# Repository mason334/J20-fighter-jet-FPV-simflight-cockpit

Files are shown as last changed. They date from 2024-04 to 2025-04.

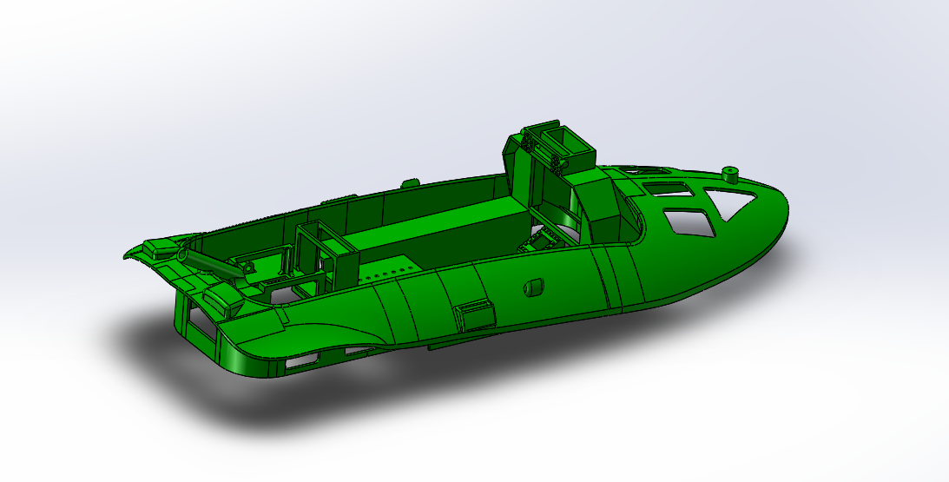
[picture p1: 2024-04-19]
3d模型 2024_4_19/座舱3d模型/座舱 spi tft 版.png

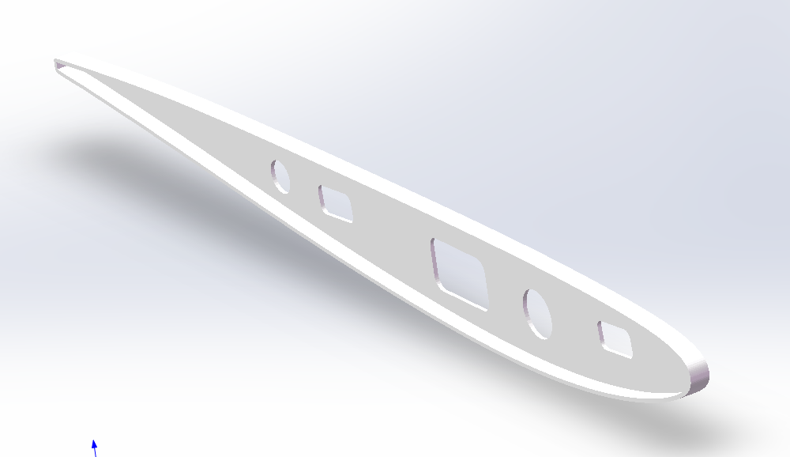
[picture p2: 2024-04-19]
3d模型 2024_4_19/新小胖3d配件/left_airfol.png

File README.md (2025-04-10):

# 5代战斗机模拟飞行座舱
## J20战机模拟座舱 Chengdu J20 fighter jet FPV simflight cockpit  
由于各种原因，最终只能有少部分人人成为飞行员，翱翔在蓝天。但是，我们依然向往飞行！  
多亏半导体和无线电技术的高速发展，已经让FPV飞行成为可能。  
现在，我们把飞行体验往前再推进一步。  
采用这套模拟座舱系统，通过3D打印和数字图传系统，你可以坐进模拟座舱，体验身临其境的战斗机驾驶乐趣。  
这套J20模拟座舱系统由硬件和软件组成。  

硬件由4部分组成  
- 机舱：包含显示器、散热风扇、DJI O3天空端等安装座。
- 舱盖：包括舱盖框架和风挡文件。
- 显示器：1块0.69寸OLDE显示器， 1块0.42寸OLED显示器，和1块2.2寸主tft lcd显示器或者1.9寸amoled主显示器。
- 显示器控制单片机：ESP32-S3  

软件部分是一套用arduino编程语言编写的ESP32-S3控制程序。ESP32-S3通过UART串口与飞控通信，采用mavlink协议。  
通过mavlink协议读取的数据，ESP32-S3驱动3块显示器显示我们想要的信息，包括姿态仪、图案、各种飞行数据。  
**这样就给一个FPV座舱注入了灵魂：实时、动态的飞行数据。**  
你甚至可以不看图传眼镜里面的OSD数据，直接通过座舱的显示器实现仪表飞行。  

## 准备工作
使用这套J20模拟座舱前，你需要具备基础的航模飞行经验，并且具备以下FPV基础硬件条件：  
- **一架天捷力 新小胖 载机**
- 一套航模飞机遥控系统  
- 一套DJI O3数字图传系统（座舱模型是根据O3数字图传系统设计的，如果采用其他图传系统，需要自行修改座舱模型）  
- 能够定义串口通信协议的飞控：例如支持ardupilot固件或者iNav固件的飞控。用于座舱和飞控的数据通信。  
- DJI FPV飞行眼镜  
如果你不具备上述条件，说明你还不适合直接开展仿真模拟FPV飞行。请先学习航模目视飞行，并学会基础的FPV知识再回来。


完成以上准备工作后，你离仿真模拟飞行的距离只差几步了，而且总共花费不到300元人民币（TFT版）。  
## 第零步，选择你喜欢的座舱版本
- 目前开发了两个版本的座舱。
- 一个是采用2.2寸tft显示屏的座舱，主显示屏成本较低（约35元）。使用文件夹“spi_tft_320_240_cockpit_20240419”里面的代码驱动2.2寸 tft显示屏。
- 另外一个版本是采用amoled的显示屏，主显示屏成本高（约190元），结果是比例更协调，亮度更高，颜色更鲜艳。使用文件夹“cockpit_lilygo_2024_4_13”里面的代码驱动lilygo amoled显示屏。这个版本的座舱还配备了光学HUD，需要一块单独的esp32单片机来驱动。使用文件夹“oled_hud_attitude_indicator_2024_4_9”里的代码来驱动这个光学hud。
- 相关视频效果见up主B站相关视频，传送连接https://space.bilibili.com/1096820983

## 第一步 打印座舱和舱盖。按照风挡文件，裁剪孰料片，制作风挡  

由于TFT LCD屏幕在阳光下亮度不够，直接在阳光下无法看清屏幕。所以风挡采用遮光塑料片，用于阳光下飞行使用。也可采用透明塑料片制作，非强光下飞行使用。

## 第二步 购买电子设备  
- ESP32-s3单片机（源地工作室，esp32-S3 N16R8)
- 信利光电 0.69寸 96x16 OLED SSD1306
- 信利光电0.42 72x40 OLED SSD1306
- 信泰微电子 2.2寸 ILI9341 SPI TFT LCD （适配SPI TFT 版座舱）
- Lilygo T-display s3 1.9寸amoled 显示屏 （适配Lilygo AMOLED版座舱）
- 光学HUD使用的显示屏采用1.5寸Futaba ELW501AAR 128*128 OLED显示屏（日本进口灰阶oled屏，类似的SSD1327芯片驱动的128X128OLED也可以）
- 盈讯 3510 液压轴承 散热风扇

## 第三步 焊接  
根据控制程序要求，焊接3块屏幕和ESP32单片机的接线。焊接ESP32单片机与飞控通信的排线。
# Lilygo T-display s3 amoled 显示屏无需焊接，屏幕和esp32单片机已经连接好

# 2.2寸显示屏接线如下  
显示屏引脚 &nbsp; &nbsp; ESP32引脚  
MISO &nbsp; &nbsp; &nbsp; &nbsp; &nbsp; &nbsp; &nbsp;13  
MOSI &nbsp; &nbsp; &nbsp; &nbsp; &nbsp; &nbsp; &nbsp;11  
SCLK &nbsp; &nbsp; &nbsp; &nbsp; &nbsp; &nbsp; &nbsp; 12  
CS &nbsp; &nbsp; &nbsp; &nbsp; &nbsp; &nbsp; &nbsp; &nbsp; &nbsp; 10  // Chip select control pin  
DC &nbsp; &nbsp; &nbsp; &nbsp; &nbsp; &nbsp; &nbsp; &nbsp; &nbsp; 7  // Data Command control pin  
RST &nbsp; &nbsp; &nbsp; &nbsp; &nbsp; &nbsp; &nbsp; &nbsp; 4  // Reset pin (could connect to RST pin)  
LED &nbsp; &nbsp; &nbsp; &nbsp; &nbsp; &nbsp; &nbsp; &nbsp; 3V3  
VCC &nbsp; &nbsp; &nbsp; &nbsp; &nbsp; &nbsp; &nbsp; &nbsp; 3V3   
GND &nbsp; &nbsp; &nbsp; &nbsp; &nbsp; &nbsp; &nbsp; &nbsp; GND  

# 0.69寸96x16显示屏接线如下  
显示屏引脚 &nbsp; &nbsp; &nbsp; ESP32引脚  
SCL/SCK &nbsp; &nbsp; &nbsp; &nbsp; &nbsp; &nbsp; 2  
SDA &nbsp; &nbsp; &nbsp; &nbsp; &nbsp; &nbsp; &nbsp; &nbsp; &nbsp; 42  
VCC &nbsp; &nbsp; &nbsp; &nbsp; &nbsp; &nbsp; &nbsp; &nbsp; &nbsp; 3V3  
GND &nbsp; &nbsp; &nbsp; &nbsp; &nbsp; &nbsp; &nbsp; &nbsp; &nbsp; GND  
# 0.42寸72x40显示屏接线如下  
显示屏引脚 &nbsp; &nbsp; &nbsp; ESP32引脚  
SCL/SCK &nbsp; &nbsp; &nbsp; &nbsp; &nbsp; &nbsp;20  
SDA &nbsp; &nbsp; &nbsp; &nbsp; &nbsp; &nbsp; &nbsp; &nbsp; &nbsp; 21  
VCC &nbsp; &nbsp; &nbsp; &nbsp; &nbsp; &nbsp; &nbsp; &nbsp; &nbsp; 3V3  
GND &nbsp; &nbsp; &nbsp; &nbsp; &nbsp; &nbsp; &nbsp; &nbsp; &nbsp; GND

# 飞控串口通讯接线
ESP32引脚 &nbsp; &nbsp; &nbsp; 飞控串口引脚  
RX &nbsp; &nbsp; &nbsp; &nbsp; &nbsp; &nbsp; &nbsp; &nbsp; &nbsp; &nbsp; TX  
GND &nbsp; &nbsp; &nbsp; &nbsp; &nbsp; &nbsp; &nbsp; &nbsp; &nbsp;GND  



## 第四步 上传代码，点亮屏幕  
将代码下载后，放到arduino项目目录下，文件夹名称与主程序文件名称一致（J20-fighter-jet-FPV-simflight-cockpit）  
安装ESP32开发板：ESP32S3 Dev Module  
根据主程序代码中include部分要求，安装所需的库文件。
Arduino已经有匹配的MAVlink库了，可以直接在arduino ide中下载安装，不再需要手动下载导入。
通过机载5V电源，给ESP32单片机供电，点亮屏幕。 **尽量不要用飞控给ESP32供电，避免飞控电流过载。**  
将代码上传到ESP32单片机。注意esp32-S3 N16R8开发板有两个type c接口，上传代码时只能用com这个口（type c接口背面有标注）  
将串口接上飞控，飞控对应的串口选择**mavlink 1**协议，获得屏幕数据。    
- SPI TFT LCD 版座舱

- Lilygo AMOLED版座舱


## 第五步 安装其他设备  
将天空端、散热风扇安装好，然后座舱盖固定到机舱上，完成安装








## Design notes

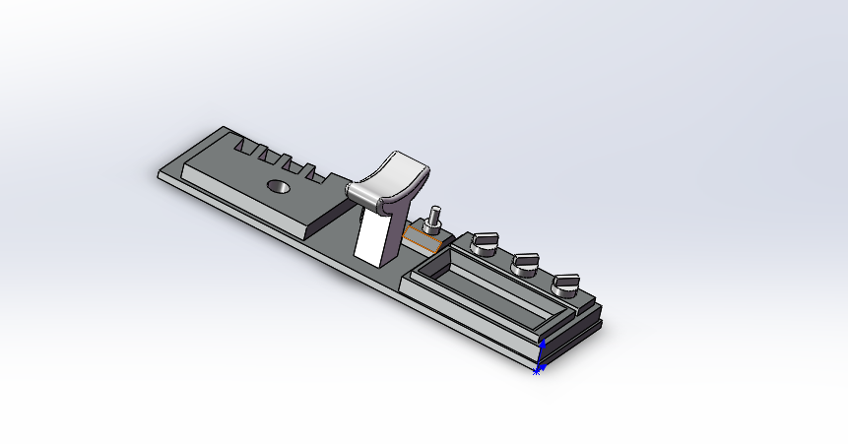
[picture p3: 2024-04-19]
3d模型 2024_4_19/座舱3d模型/right side control panel.png

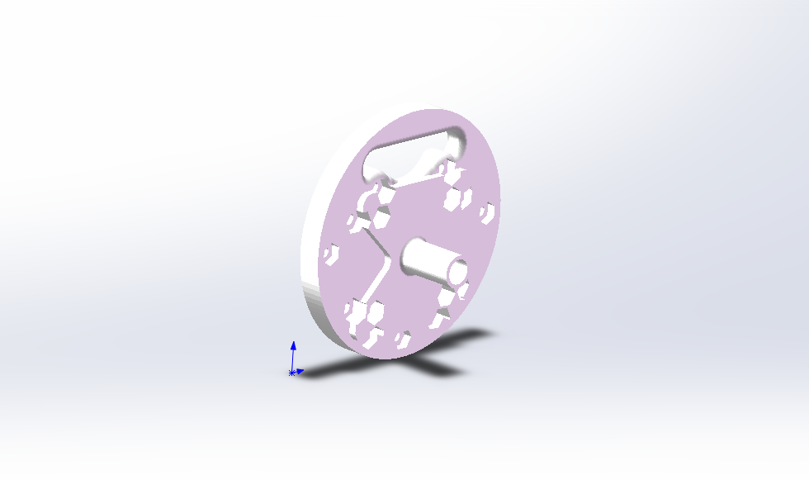
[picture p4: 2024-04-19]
3d模型 2024_4_19/新小胖3d配件/motor mount.png

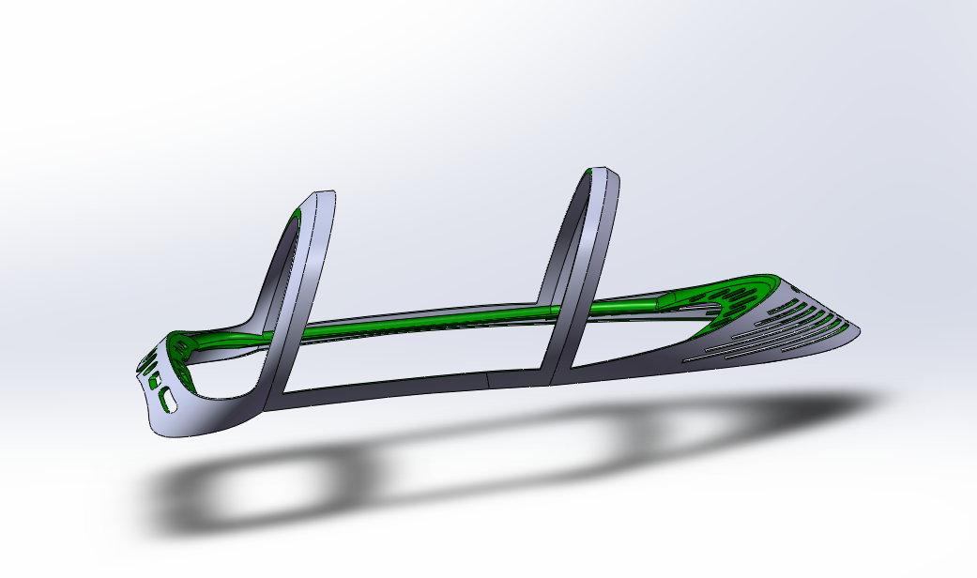
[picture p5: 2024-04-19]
3d模型 2024_4_19/座舱3d模型/舱盖 不含进气道.png

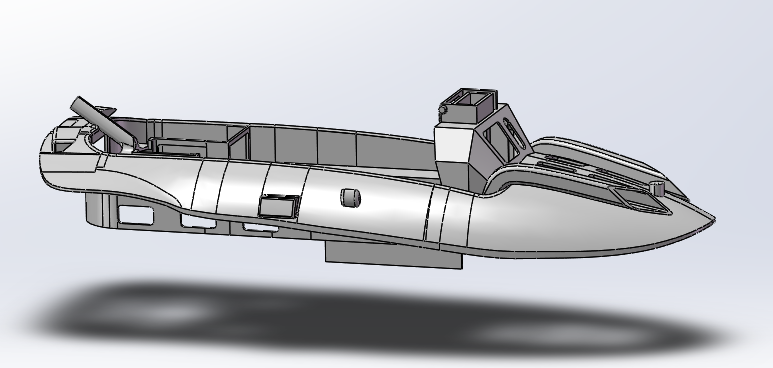
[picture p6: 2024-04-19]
3d模型 2024_4_19/座舱3d模型/座舱 spi tft版 含进气道.png

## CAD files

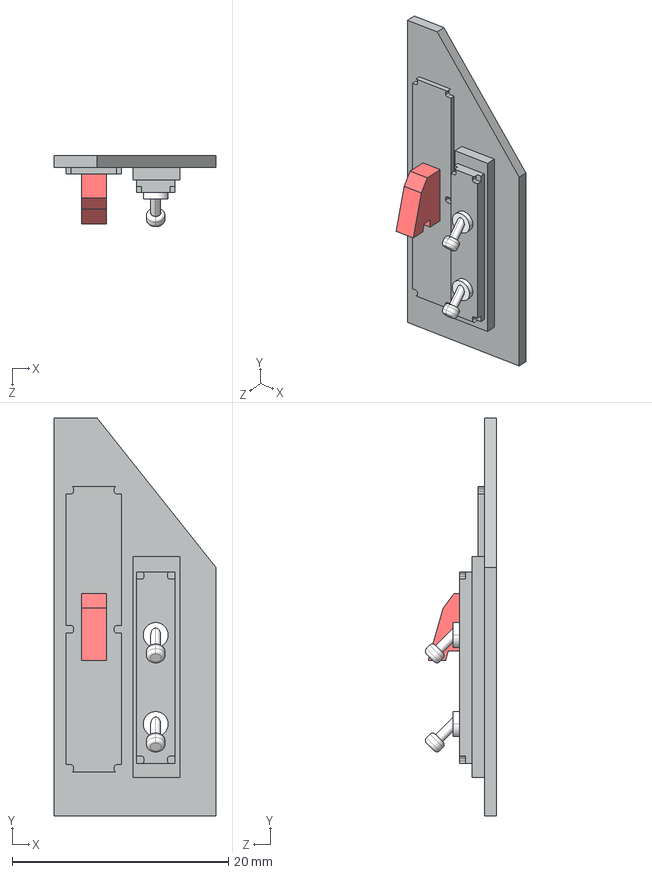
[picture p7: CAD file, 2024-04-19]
3d模型 2024_4_19/座舱3d模型/main screen right side panel.STEP
14.9 x 36.8 x 6.61 mm

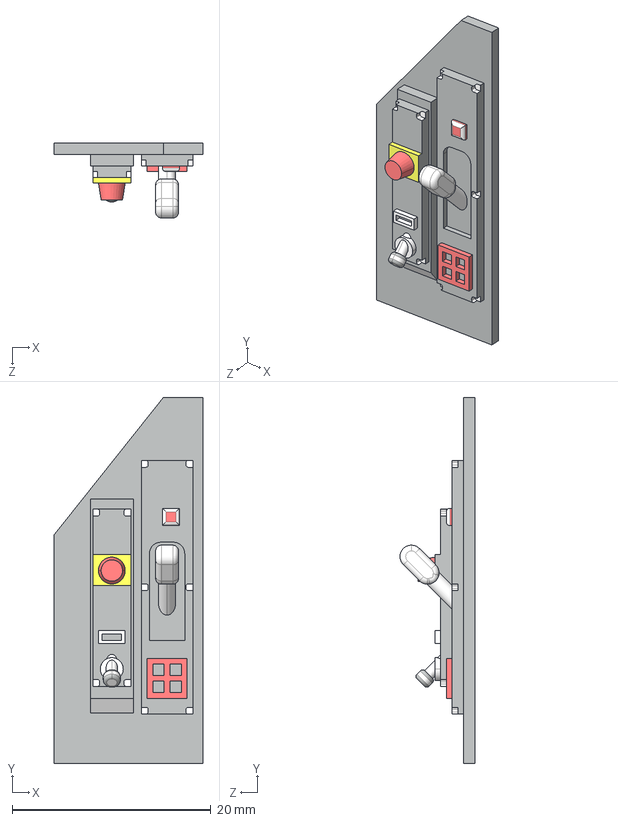
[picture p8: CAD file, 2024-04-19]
3d模型 2024_4_19/座舱3d模型/main screen left side panel.STEP
14.9 x 36.8 x 7.54 mm

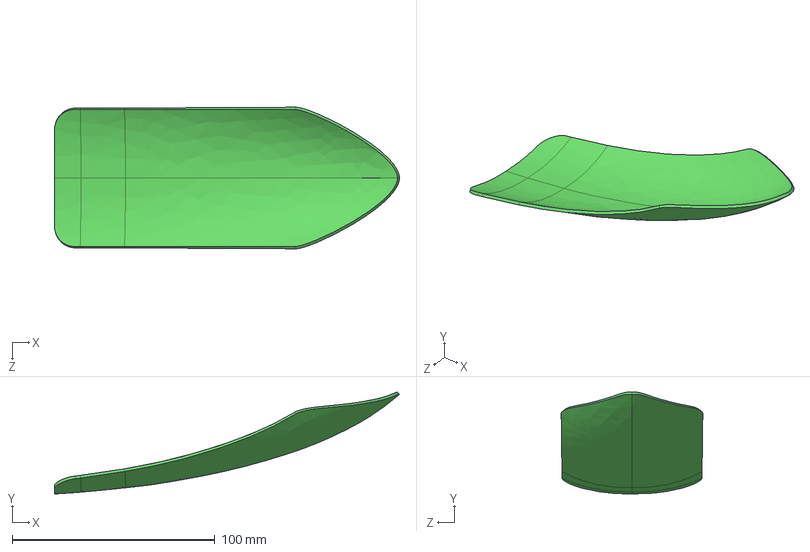
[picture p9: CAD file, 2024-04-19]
3d模型 2024_4_19/新小胖3d配件/fuselage armor.STEP
170.1 x 50.3 x 69.8 mm

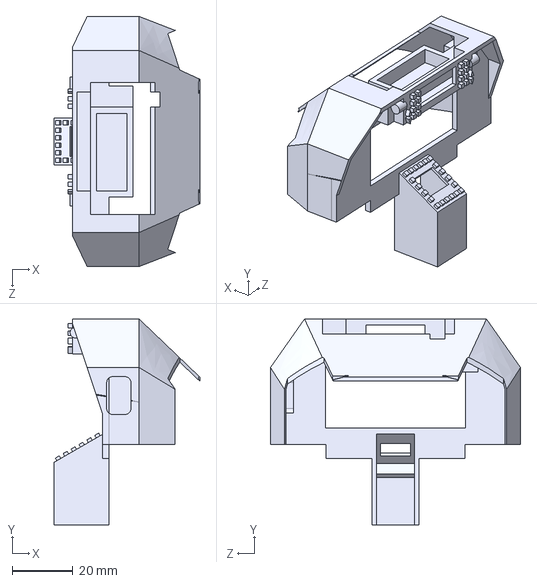
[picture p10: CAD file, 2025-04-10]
J20座舱3D模型 适配新小胖 2025-4/新小胖 j20座舱 3D模型 2025-4/驾驶室主控制面板.STEP
48.0 x 67.9 x 82.5 mm

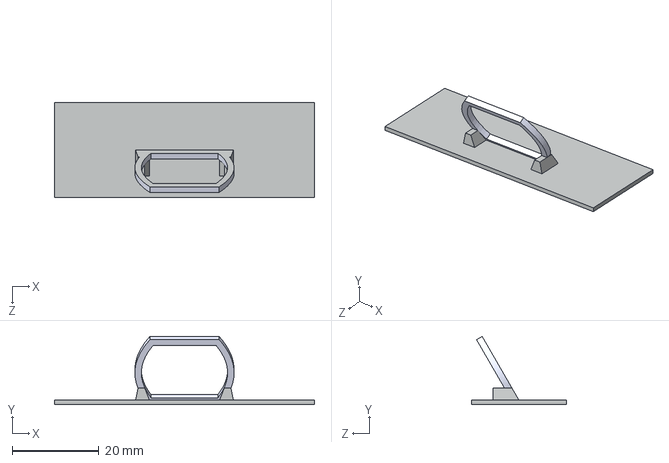
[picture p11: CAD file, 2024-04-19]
3d模型 2024_4_19/座舱3d模型/装饰hud 适配 lilygo amoled版 座舱.STEP
60.0 x 15.7 x 22.0 mm

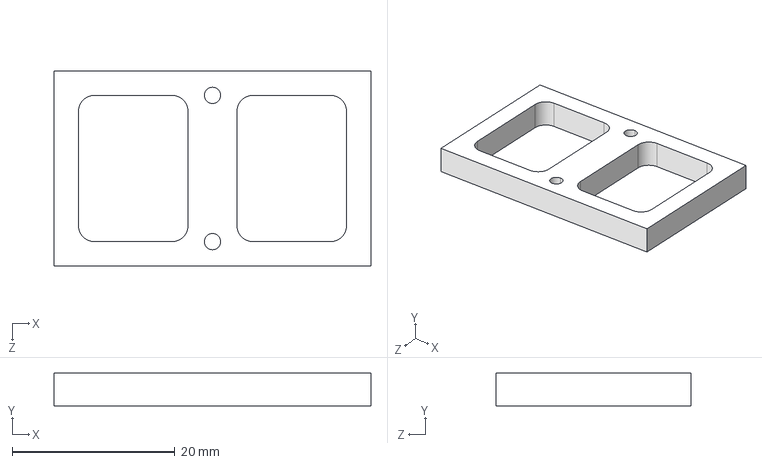
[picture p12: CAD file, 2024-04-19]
3d模型 2024_4_19/新小胖3d配件/ptz servo mount spacer.STEP
39.0 x 4.00 x 24.0 mm

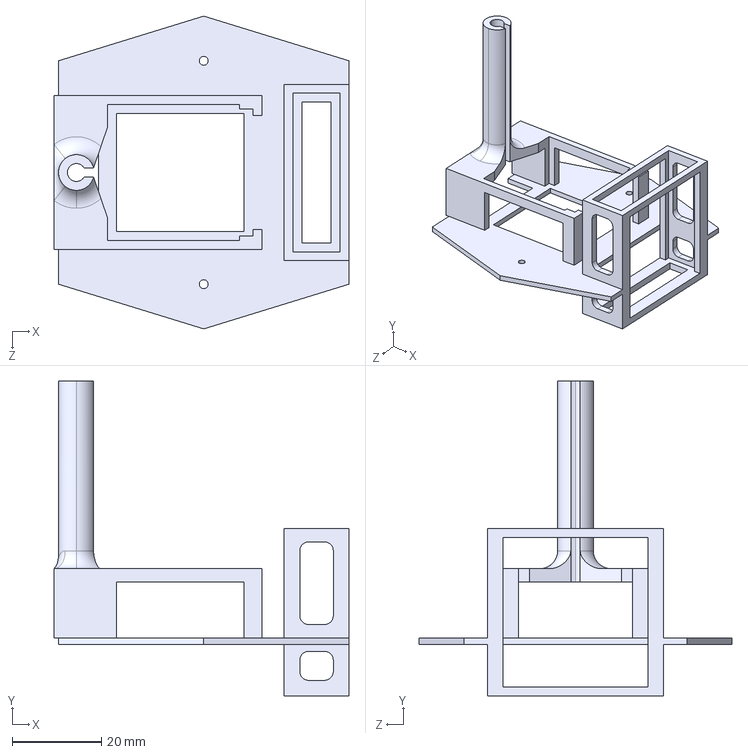
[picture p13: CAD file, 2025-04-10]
J20座舱3D模型 适配新小胖 2025-4/新小胖 j20座舱 3D模型 2025-4/o3天空端架和风扇架.STEP
66.0 x 70.5 x 70.0 mm

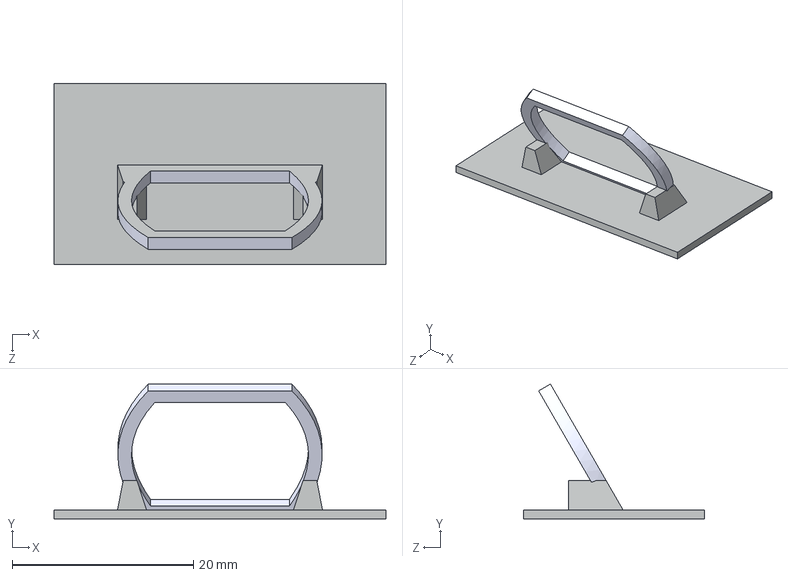
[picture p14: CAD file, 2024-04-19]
3d模型 2024_4_19/座舱3d模型/装饰hud 适配 spi tft版座舱.STEP
36.6 x 14.9 x 20.0 mm

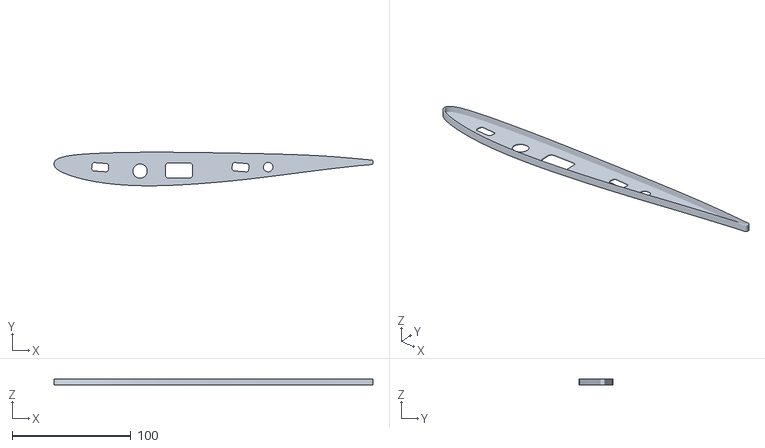
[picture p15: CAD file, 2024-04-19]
3d模型 2024_4_19/新小胖3d配件/rightairfol.stl
268.2 x 28.3 x 5.00

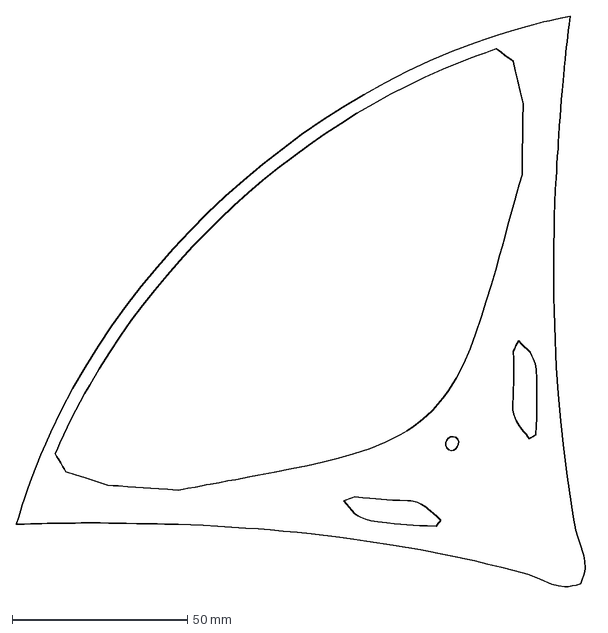
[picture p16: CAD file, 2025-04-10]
J20座舱3D模型 适配新小胖 2025-4/新小胖 j20座舱 3D模型 2025-4/前风挡.DXF
164.1 x 164.4 mm

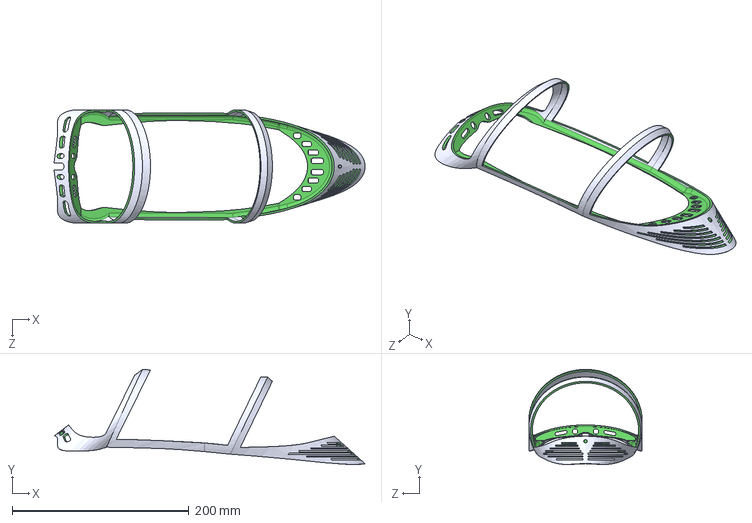
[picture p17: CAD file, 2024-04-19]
3d模型 2024_4_19/座舱3d模型/舱盖 不含进气道.STEP
351.9 x 107.7 x 128.3 mm

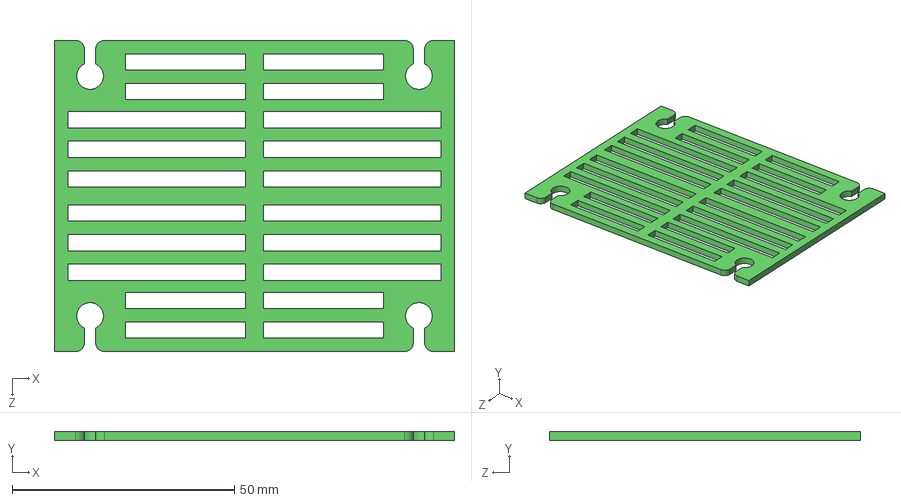
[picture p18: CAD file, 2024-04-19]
3d模型 2024_4_19/新小胖3d配件/flight controller bay upper part.STEP
90.0 x 2.00 x 70.0 mm

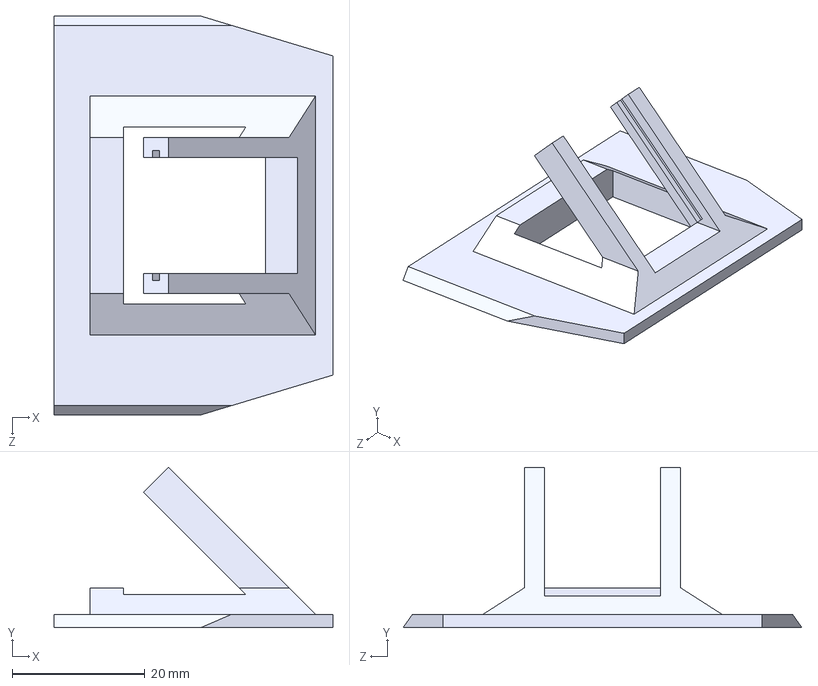
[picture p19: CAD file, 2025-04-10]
J20座舱3D模型 适配新小胖 2025-4/新小胖 j20座舱 3D模型 2025-4/hud.STEP
41.9 x 24.1 x 60.0 mm

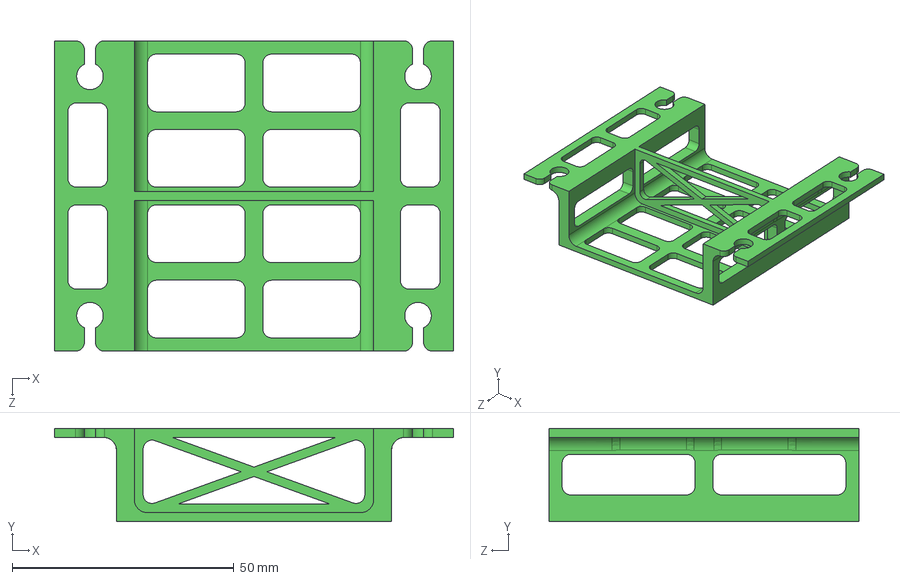
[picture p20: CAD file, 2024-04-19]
3d模型 2024_4_19/新小胖3d配件/flight controller bay lower part.STEP
90.0 x 21.0 x 70.0 mm

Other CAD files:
J20座舱3D模型 适配新小胖 2025-4/新小胖 j20座舱 3D模型 2025-4/后风挡.DXF
3d模型 2024_4_19/座舱3d模型/光学hud 适配 lilygo amoled版 座舱.STEP
3d模型 2024_4_19/新小胖3d配件/9g servo adapter.STEP
J20座舱3D模型 适配新小胖 2025-4/新小胖 j20座舱 3D模型 2025-4/舱盖.STEP
3d模型 2024_4_19/座舱3d模型/control stick.STEP
3d模型 2024_4_19/座舱3d模型/left side control panel.STEP
3d模型 2024_4_19/座舱3d模型/right side control panel.STEP
3d模型 2024_4_19/座舱3d模型/舱盖 适配 含进气道 座舱.STEP
3d模型 2024_4_19/新小胖3d配件/Battery Bay.STEP
3d模型 2024_4_19/新小胖3d配件/Motor_mount.STL
3d模型 2024_4_19/新小胖3d配件/leftairfol.stl
3d模型 2024_4_19/新小胖3d配件/ptz servo mount.STEP
J20座舱3D模型 适配新小胖 2025-4/新小胖 j20座舱 3D模型 2025-4/中风挡.DXF

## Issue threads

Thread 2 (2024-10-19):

老哥关于反射hub的接线方式并未给出，可以补充一下吗？谢谢

SongSop, 2024-10-19:

mason334, 2024-10-21:
加qq群，群里讨论解答方便，217107609

邹雪骢
电话：177-1791-4477
***@***.***

---- 回复的原邮件 ----
| 发件人 | ***@***.***> |
| 发送日期 | 2024年10月19日 12:25 |
| 收件人 | mason334/J20-fighter-jet-FPV-simflight-cockpit ***@***.***> |
| 抄送人 | Subscribed ***@***.***> |
| 主题 | [mason334/J20-fighter-jet-FPV-simflight-cockpit] 老哥关于反射hub的接线方式并未给出，可以补充一下吗？谢谢 (Issue #2) |

—
Reply to this email directly, view it on GitHub, or unsubscribe.
You are receiving this because you are subscribed to this thread.Message ID: ***@***.***>

jianwwpro, 2025-02-27:
SDA -> GPIO 21
SCL -> GPIO 22
VCC -> 3.3V
GND -> GND

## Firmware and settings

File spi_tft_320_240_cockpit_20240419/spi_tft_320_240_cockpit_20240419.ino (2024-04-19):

/*
驱动主屏幕注意事项，请务必阅读
ILI9341 library example
(c) 2020 Pawel A. Hernik
 ILI9341 240x320 2.2" tft pinout (header at the top, from left):

引脚定义如下
GND   -> GND
VCC   -> 3.3V
其他的引脚在Arduino\libraries\TFT_eSPI\User_Setup.h文件中修改
###### EDIT THE PIN NUMBERS IN THE LINES FOLLOWING TO SUIT YOUR ESP32 SETUP   ######
For ESP32 Dev board (only tested with ILI9341 display)
The hardware SPI can be mapped to any pins
#define TFT_MISO 13
#define TFT_MOSI 11
#define TFT_SCLK 12
#define TFT_CS   10  // Chip select control pin
#define TFT_DC    7  // Data Command control pin
#define TFT_RST   4  // Reset pin (could connect to RST pin)
*/


#include <Arduino.h>
#define SCR_WD   240
#define SCR_HT   240

#include <SPI.h>
#include <Adafruit_GFX.h>
#include <MAVLink.h>
#include "TFT_eSPI.h"
#include <math.h>
#include <PNGdec.h>
#include "pictures.h" // Image is stored here in an 8 bit array
#include <U8g2lib.h>
#include "cockpit_var.h"

// 双核运行所需handle，用于追踪执行情况
TaskHandle_t Task1;
TaskHandle_t Task2;

PNG png; // PNG decoder instance

TFT_eSPI tft = TFT_eSPI();
TFT_eSprite spr = TFT_eSprite(&tft);  // Declare Sprite object "spr" with pointer to "tft" object
TFT_eSprite spr2 = TFT_eSprite(&tft);  // Declare Sprite object "spr" with pointer to "tft" object
TFT_eSprite spr3 = TFT_eSprite(&tft);
TFT_eSprite spr4 = TFT_eSprite(&tft);
TFT_eSprite spr5 = TFT_eSprite(&tft);
TFT_eSprite spr6 = TFT_eSprite(&tft);

//定义最上方副显示屏（1号屏）的虚拟对象，起名u8g1。
// U8G2_SSD1306_96X16_ER_F_SW_I2C u8g1(U8G2_R0, /* clock=*/ 2, /* data=*/ 42, /* reset=*/ U8X8_PIN_NONE);  
U8G2_SSD1306_96X16_ER_F_HW_I2C u8g1(U8G2_R0, /* reset=*/ U8X8_PIN_NONE, /* clock=*/ 2, /* data=*/ 42); //1号屏用硬件I2C协议，FPS高，用于显示电流数据。

//定义下方副显示屏（2号屏）的虚拟对象，起名u8g2。 无法同时开启两个硬件I2C协议，2号屏用软件I2C协议，FPS较低。
U8G2_SSD1306_72X40_ER_F_SW_I2C u8g2(U8G2_R0, /* clock=*/ 20, /* data=*/ 21, /* reset=*/ U8X8_PIN_NONE);  

void setup() {
  // put your setup code here, to run once:
  u8g2.enableUTF8Print();
  u8g1.enableUTF8Print();
  pinMode(19, OUTPUT);
  digitalWrite(19, HIGH);
  pinMode(1, OUTPUT);
  digitalWrite(1, HIGH);
  
  u8g1.begin();
  u8g2.begin();
  u8g1.setFont(u8g2_font_wqy16_t_gb2312b);
  u8g2.setFont(u8g2_font_wqy16_t_gb2312b);
  Serial.begin(57600);
  tft.init();

  spr.createSprite(x_limit, y_limit);  //attitude indicator
  spr2.createSprite(x_limit, y_limit); // 各种参数
  spr3.createSprite(70, 33);  //卫星个数
  spr5.createSprite(70, 33);  //电压
  spr6.createSprite(70, 33);  //速度
  spr4.createSprite(222, 40); //左下角 roll pitch

  tft.setRotation(1);
  screen_init();   


  xTaskCreatePinnedToCore(
                  Task1code,   /* Task function. */
                  "Task1",     /* name of task. */
                  10000,       /* Stack size of task */
                  NULL,        /* parameter of the task */
                  1,           /* priority of the task */
                  &Task1,      /* Task handle to keep track of created task */
                  0);          /* pin task to core 0 */     


  //create a task that will be executed in the Task2code() function, with priority 1 and executed on core 1
  xTaskCreatePinnedToCore(
                    Task2code,   /* Task function. */
                    "Task2",     /* name of task. */
                    10000,       /* Stack size of task */
                    NULL,        /* parameter of the task */
                    1,           /* priority of the task */
                    &Task2,      /* Task handle to keep track of created task */
                    1);          /* pin task to core 1 */

}

// task1code, 显示主显示屏信息
void Task1code( void * pvParameters ){
  // Serial.print("Task1 running on core ");
  // Serial.println(xPortGetCoreID());

  for(;;){
    get_mavlink_data();
    cal_att_cord();
    draw_new_attitude();
    draw_main_screen();
    spr.pushSprite(0, 35);  //attitude indicator       
    spr2.pushSprite(112,35); //各种参数
    spr4.pushSprite(0,200); //左下角 roll pitch
    spr3.pushSprite(40, 0); //卫星个数
    spr5.pushSprite(150, 0); //电压
    spr6.pushSprite(265, 0); //速度

    //计算主屏幕的fps3
    // now3 = millis();
    // frameCount3 ++;
    // if (now3 - Millis3rd >= 5000){
    //   fps3 = frameCount3/5;
    //   frameCount3 = 0;   
    //   Millis3rd = now3;        
    // }
      
  } 
}

//Task2code: 显示2、3屏幕信息
void Task2code( void * pvParameters ){
  // Serial.print("Task2 running on core ");
  // Serial.println(xPortGetCoreID());
  for(;;){
    //计算屏幕2的fps2,同时推送u8g2屏幕的信息
    now2 = millis();
    if (now2 - Millis2nd >= 1000){
    push_u8g2_fltmode();
    Millis2nd = now2;            
    }

    // 计算屏幕fps1
    now1 = millis();  
    frameCount1 ++;
    if (now1 - Millis1st >= 1000){
      fps1 = frameCount1;
      frameCount1 = 0;
      Millis1st = now1;             
    }   
    
  // 用上面1屏幕显示DC电流     
  push_u8g1_current();        
  }
}

void loop(void) {  

} // void loop

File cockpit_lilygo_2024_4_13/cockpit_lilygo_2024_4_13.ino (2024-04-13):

#include <Arduino.h>

#include <Adafruit_GFX.h>
#include <MAVLink.h>
#include "TFT_eSPI.h"
#include <math.h>
#include <U8g2lib.h>

#ifdef U8X8_HAVE_HW_SPI
#include <SPI.h>
#endif

#ifdef U8X8_HAVE_HW_I2C
#include <Wire.h>  //hardware I2C need this library
#endif

#include "rm67162.h"
#include "cockpit_var.h"

#include "tftespi_cn_fonts.h"
#include "tftespi_en_fonts.h"
#include "j20_109_182.h" //歼20图标
#include "salt_45_43.h" //GPS卫星图标



// 双核运行所需handle，用于追踪执行情况
TaskHandle_t Task1;
TaskHandle_t Task2;


TFT_eSPI tft = TFT_eSPI();
TFT_eSprite spr = TFT_eSprite(&tft);  // Declare Sprite object "spr" with pointer to "tft" object
TFT_eSprite spr_meters = TFT_eSprite(&tft);
TFT_eSprite spr_meters_2 = TFT_eSprite(&tft);
TFT_eSprite spr_jet = TFT_eSprite(&tft);
TFT_eSprite spr_status = TFT_eSprite(&tft);
TFT_eSprite spr_left_bar = TFT_eSprite(&tft);
TFT_eSprite spr_left_rec = TFT_eSprite(&tft);
TFT_eSprite spr_right_bar = TFT_eSprite(&tft);
TFT_eSprite spr_right_rec = TFT_eSprite(&tft);
TFT_eSprite spr_mid = TFT_eSprite(&tft);


//定义下方副显示屏（2号屏）的虚拟对象，起名u8g2。无法同时开启两个硬件I2C协议，用软件I2C。FPS较低。
U8G2_SSD1306_72X40_ER_F_SW_I2C u8g2(U8G2_R0, /* clock=*/ 41, /* data=*/ 40, /* reset=*/ U8X8_PIN_NONE);  


//定义最上方副显示屏（1号屏）的虚拟对象，起名u8g1。1号屏用硬件I2C协议，FPS高，用于显示电流数据。
U8G2_SSD1306_96X16_ER_F_HW_I2C u8g1(U8G2_R0, /* reset=*/ U8X8_PIN_NONE, /* clock=*/ 1, /* data=*/ 2);


void setup() {

  rm67162_init(); 
  lcd_setRotation(1);  
  u8g1.begin();
  u8g2.begin();
  u8g1.enableUTF8Print();
  u8g2.enableUTF8Print();

  u8g1.setFont(u8g2_font_wqy16_t_gb2312b);
  u8g2.setFont(u8g2_font_wqy16_t_gb2312b);

  Serial.begin(57600);

  spr.createSprite(165, 240);  //attitude indicator
  spr_meters.createSprite(80, 240);
  spr_meters_2.createSprite(80, 240);
  spr_jet.createSprite(109, 182);
  spr_mid.createSprite(200, 240);
  spr_status.createSprite(109, 53);
  spr_right_bar.createSprite(50, 180);
  spr_left_bar.createSprite(50, 180);
  spr_right_rec.createSprite(80, 40);
  spr_left_rec.createSprite(80, 40);


xTaskCreatePinnedToCore(
                  Task1code,   /* Task function. */
                  "Task1",     /* name of task. */
                  10000,       /* Stack size of task */
                  NULL,        /* parameter of the task */
                  1,           /* priority of the task */
                  &Task1,      /* Task handle to keep track of created task */
                  0);          /* pin task to core 0 */     


  //create a task that will be executed in the Task2code() function, with priority 1 and executed on core 1
xTaskCreatePinnedToCore(
                    Task2code,   /* Task function. */
                    "Task2",     /* name of task. */
                    10000,       /* Stack size of task */
                    NULL,        /* parameter of the task */
                    1,           /* priority of the task */
                    &Task2,      /* Task handle to keep track of created task */
                    1);          /* pin task to core 1 */

}

// task1code, 显示主显示屏信息
void Task1code( void * pvParameters ){
  //task 的时间不能太短，否则会触发task watchdog,导致芯片重启
  // Serial.print("Task1 begines on core ");
  // Serial.println(xPortGetCoreID());
  for(;;){
    vTaskDelay(1); //disable task watchdog
    // Serial.print("Task1 running on core ");
    // Serial.println(xPortGetCoreID());

    push_main_screen();
    adjust_brightness_main();

    // 计算主屏幕fps0
    frameCount0 ++;
    now0 = millis();
    if (now0 - Millis0 >= 2000){
      fps0 = frameCount0/2;
      frameCount0 = 0;   
      Millis0 = now0;      
    }      
  } 
}

// Task2code: 显示1、2屏幕信息
void Task2code( void * pvParameters ){

  for(;;){
    vTaskDelay(1);
    // Serial.print("Task2 running on core ");
    // Serial.println(xPortGetCoreID());
    push_u8g1();
    adjust_brightness_small();

    now1 = millis();
    frameCount1 ++;
    if (now1 - Millis1st >= 1000){
      fps1 = frameCount1;
      frameCount1 = 0;   
      Millis1st = now1;

      push_u8g2();
    }
  }
}

void loop(void) {  
  
} // void loop

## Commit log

2023-08-24 Update J20-fighter-jet-FPV-simflight-cockpit.ino
    给需要安装的库加上了注释
2023-08-24 Update README.md
    加上了接线方法和代码运行方法
2024-04-13 Add files via upload
    第一次上传lilygo版本的座舱代码
2024-04-13 Add files via upload
    透明HUD的代码
2025-04-10 Create 新小胖 j20座舱 3D模型 2025-4
